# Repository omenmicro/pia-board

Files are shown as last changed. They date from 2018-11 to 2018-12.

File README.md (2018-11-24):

#OMEN PIA

Two 8bit serial port, designed for the [OMEN Computers](//github.com/osmibity/) with the system bus (Alpha, Bravo, Kilo, ...)

It uses the Motorola 68B21 PIA chip, or its 65xx equivalent 6521 (available from the WDC as [W65C21](http://westerndesigncenter.com/wdc/w65c21-chip.cfm)).

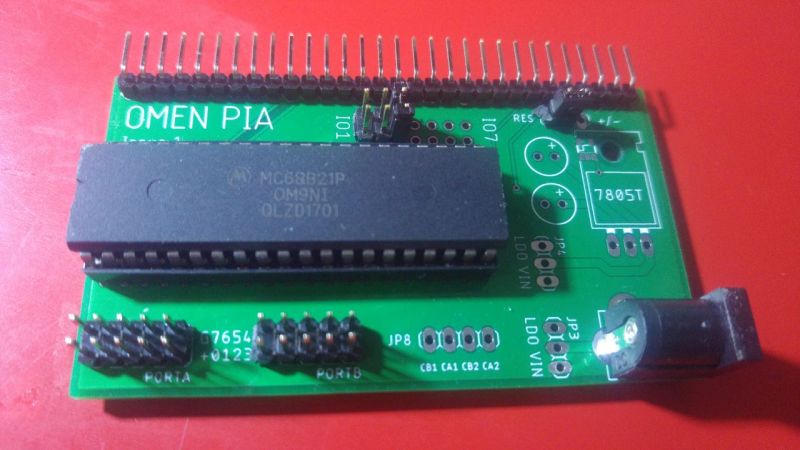
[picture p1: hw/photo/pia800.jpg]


Board allows some options:

- Power supply
  - Direct supply for 5 V
  - Voltage regulator for supply 7 - 12 V
- RESET invertor (OMEN Alpha has positive RESET, others have inverted /RESET)
- IO selector (you can select IO1 to IO7 using simple switch)

## Parts

- Motorola MC68B21 or equivalent (W65C21, R6521 etc)
- IO socket DIL, 40 pin, wide
- Pin headers for the OMEN Bus, IO switch, port data pins
- Switches for LDO and RESET polarity
- (Optionally) 7805 LDO voltage regulator + 2x capacitor 10M
- (Optionally) SMD invertor 74AHC1G04D for reverting the RESET polarity

## Usage

Select the right IOx address space. For addresses value of each IOx, consult your OMEN manual.

See [datasheet](docs/datasheet) to further detail about programming.

## Ports

Ports are connected to 2x5 pin header each. 

Each header has 8 data pin, Vcc and GND.

Special header JP8 has connected the CA1, CA2, CB1 and CB2 control pins.

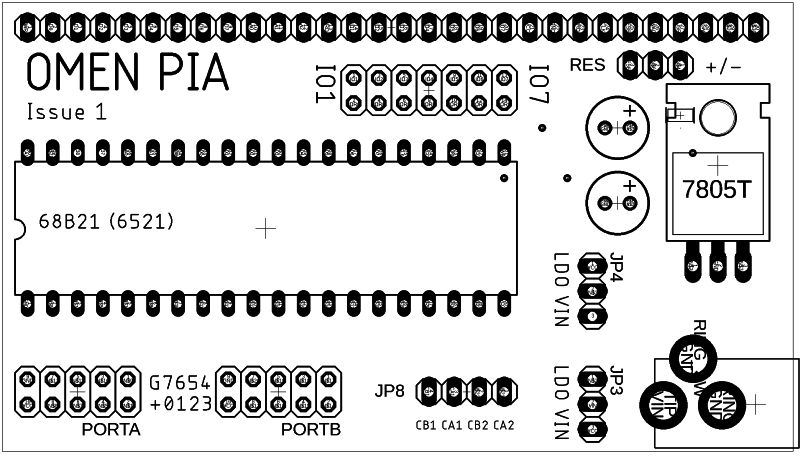
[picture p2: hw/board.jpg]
Board


### RESET circuit

For Kilo, Bravo etc. with inverted RESET, just connect RES pin "+" (1-2)
For Alpha: Solder the invertor 74AHC1G04D and connect RES pin "-" (2-3)
Alpha hack: just solder a wire between the middle pin of RES switch and VCC (e.g. pin 20 of PIA IC)

### Power circuit

If you have the regulated voltage supply 5V, you can connect it directly here. Please use two switches (JP3, JP4), both on "VIN" position. *CAUTION! Supply input is connected directly to the system Vcc, so leave the supply input on the CPU board not connected!*

You can use the place for the 7805 regulator (up to 2 A). Solder the regulator and tvo capacitors, and select option "LDO" on both switches JP3, JP4. Connect power supply 7 - 12 V. Use heat sink for the regulator!

If you does not use the dedicated power supply, just leave both switches open and omit the power supply connector, voltage regulator as well as both capacitors.

## System bus pinout

| Pin | Signal
| --- | ---
| 1  | /WR
| 2  | D0
| 3  | D1
| 4  | D2
| 5  | D3
| 6  | D4
| 7  | D5
| 8  | D6
| 9  | D7
| 10 |  A0
| 11 |  A1
| 12 |  A2 (not connected in OMEN PIA)
| 13 |  /RD
| 14 |  IO1 (active low)
| 15 |  IO2
| 16 |  IO3
| 17 |  IO4
| 18 |  IO5
| 19 |  IO6
| 20 |  IO7
| 21 |  Vcc
| 22 |  GND
| 23 |  IRQ (not connected in OMEN PIA)
| 24 |  Clock
| 25 |  /RESET
| 26 |  /WAIT (not connected in OMEN PIA)
| 27 |  /BUSRQ (not connected in OMEN PIA)
| 28 |  /BUSACK (not connected in OMEN PIA)
| 29 |  (Reserved for future use)
| 30 |  (Reserved for future use)

### License

[CERN OHL](LICENSE.txt)

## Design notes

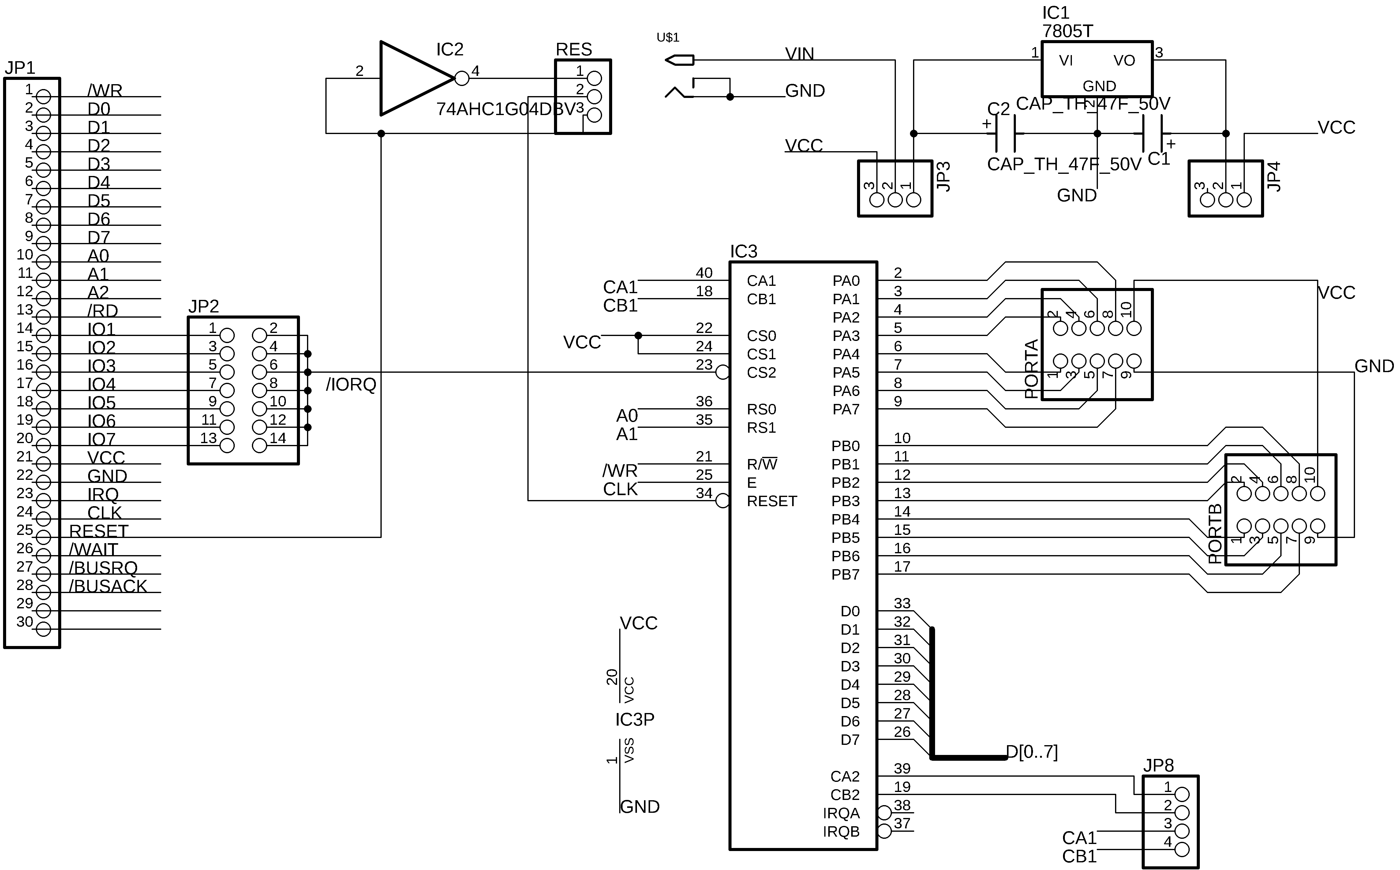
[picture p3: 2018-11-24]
hw/omenpia-schematics.png

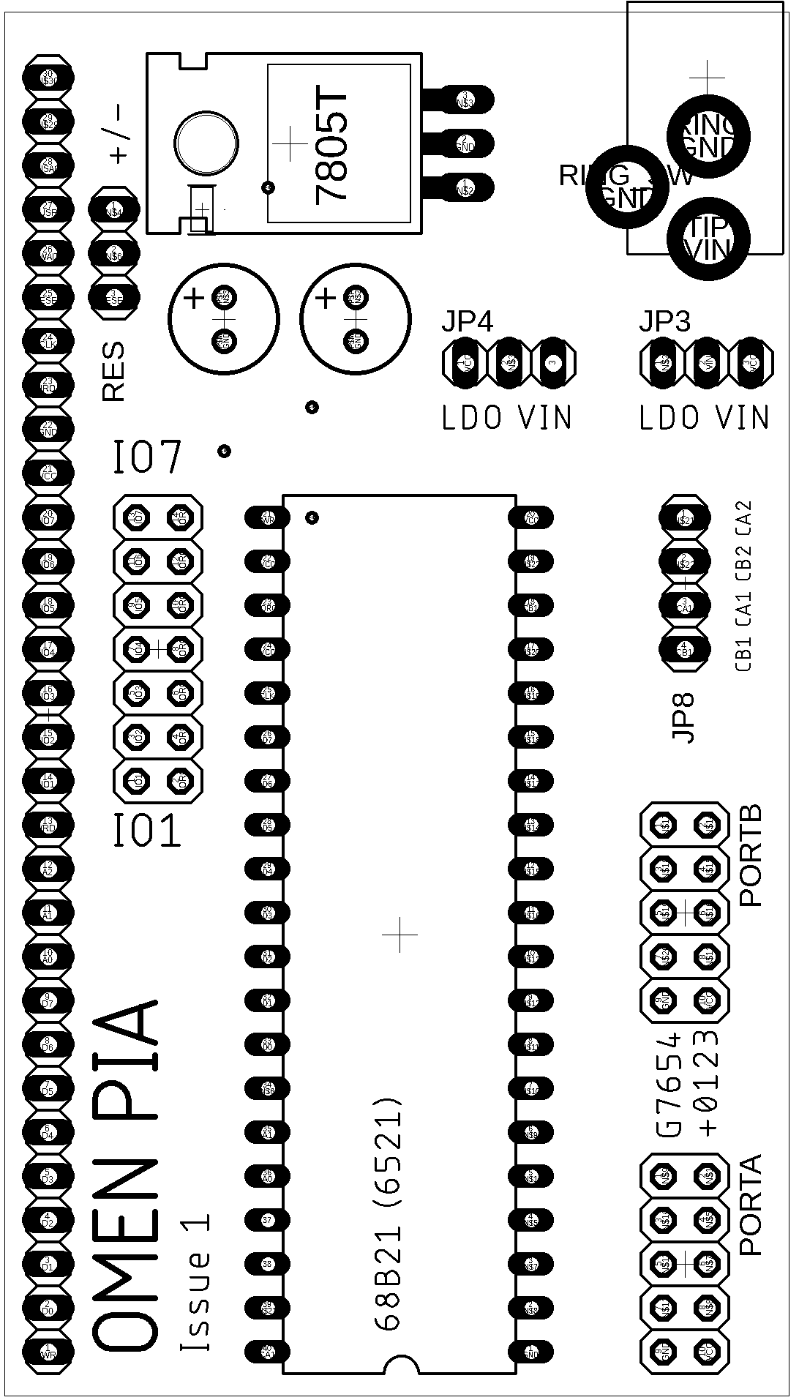
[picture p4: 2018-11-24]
hw/omenpia-board.png

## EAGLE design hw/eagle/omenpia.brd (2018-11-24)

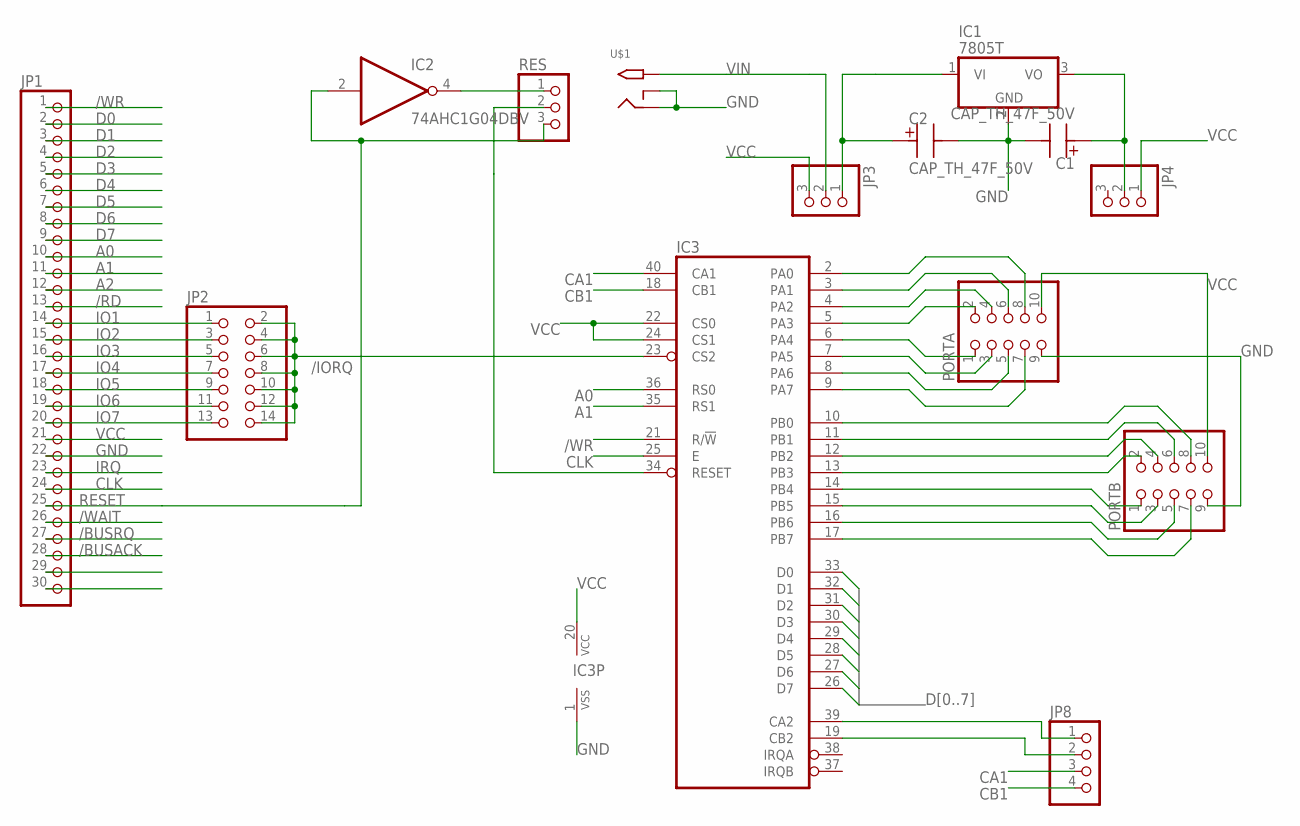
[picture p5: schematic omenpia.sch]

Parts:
C1, C2: CAP_TH_47F_50V; CAP_TH_P25_D63_POL
IC1: 7805T; TO220H
IC2: 74AHC1G04DBV; SOT23-5
IC3: 6821; DIL40
JP1: PINHD-1X30; 1X30
JP2: PINHD-2X7; 2X07
JP3, JP4: PINHD-1X3; 1X03
JP8: PINHD-1X4; 1X04
PORTA: PINHD-2X5; 2X05
PORTB: PINHD-2X5; 2X05
RES: PINHD-1X3; 1X03
U$1: 2.1MMJACKTHM; PJ-102A

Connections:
/BUSACK: JP1.28
/BUSRQ: JP1.27
/IORQ: IC3.23 (CS2), JP2.2, JP2.4, JP2.6, JP2.8, JP2.10, JP2.12, JP2.14
/RD: JP1.13
/WAIT: JP1.26
/WR: IC3.21 (R/!W), JP1.1
A0: IC3.36 (RS0), JP1.10
A1: IC3.35 (RS1), JP1.11
A2: JP1.12
CA1: IC3.40 (CA1), JP8.3
CB1: IC3.18 (CB1), JP8.4
CLK: IC3.25 (E), JP1.24
D0: IC3.33 (D0), JP1.2
D1: IC3.32 (D1), JP1.3
D2: IC3.31 (D2), JP1.4
D3: IC3.30 (D3), JP1.5
D4: IC3.29 (D4), JP1.6
D5: IC3.28 (D5), JP1.7
D6: IC3.27 (D6), JP1.8
D7: IC3.26 (D7), JP1.9
GND: C1.P$M, C2.P$M, IC1.2 (GND), IC2.3 (GND), IC3.1 (VSS), JP1.22, PORTA.9, PORTB.9, U$1.RING, U$1.RING_SW
IO1: JP1.14, JP2.1
IO2: JP1.15, JP2.3
IO3: JP1.16, JP2.5
IO4: JP1.17, JP2.7
IO5: JP1.18, JP2.9
IO6: JP1.19, JP2.11
IO7: JP1.20, JP2.13
IRQ: JP1.23
unnamed: IC3.5 (PA3), PORTA.2
unnamed: C2.P$P, IC1.1 (VI), JP3.1
unnamed: C1.P$P, IC1.3 (VO), JP4.2
unnamed: IC2.4 (O), RES.1
unnamed: IC3.4 (PA2), PORTA.4
unnamed: IC3.34 (RESET), RES.2
unnamed: IC3.3 (PA1), PORTA.6
unnamed: IC3.2 (PA0), PORTA.8
unnamed: IC3.6 (PA4), PORTA.1
unnamed: IC3.7 (PA5), PORTA.3
unnamed: IC3.8 (PA6), PORTA.5
unnamed: IC3.9 (PA7), PORTA.7
unnamed: IC3.10 (PB0), PORTB.8
unnamed: IC3.13 (PB3), PORTB.2
unnamed: IC3.12 (PB2), PORTB.4
unnamed: IC3.11 (PB1), PORTB.6
unnamed: IC3.14 (PB4), PORTB.1
unnamed: IC3.15 (PB5), PORTB.3
unnamed: IC3.16 (PB6), PORTB.5
unnamed: IC3.17 (PB7), PORTB.7
unnamed: IC3.39 (CA2), JP8.1
unnamed: IC3.19 (CB2), JP8.2
RESET: IC2.2 (I), JP1.25, RES.3
VCC: IC2.5 (VCC), IC3.20 (VCC), IC3.22 (CS0), IC3.24 (CS1), JP1.21, JP3.3, JP4.1, PORTA.10, PORTB.10
VIN: JP3.2, U$1.TIP

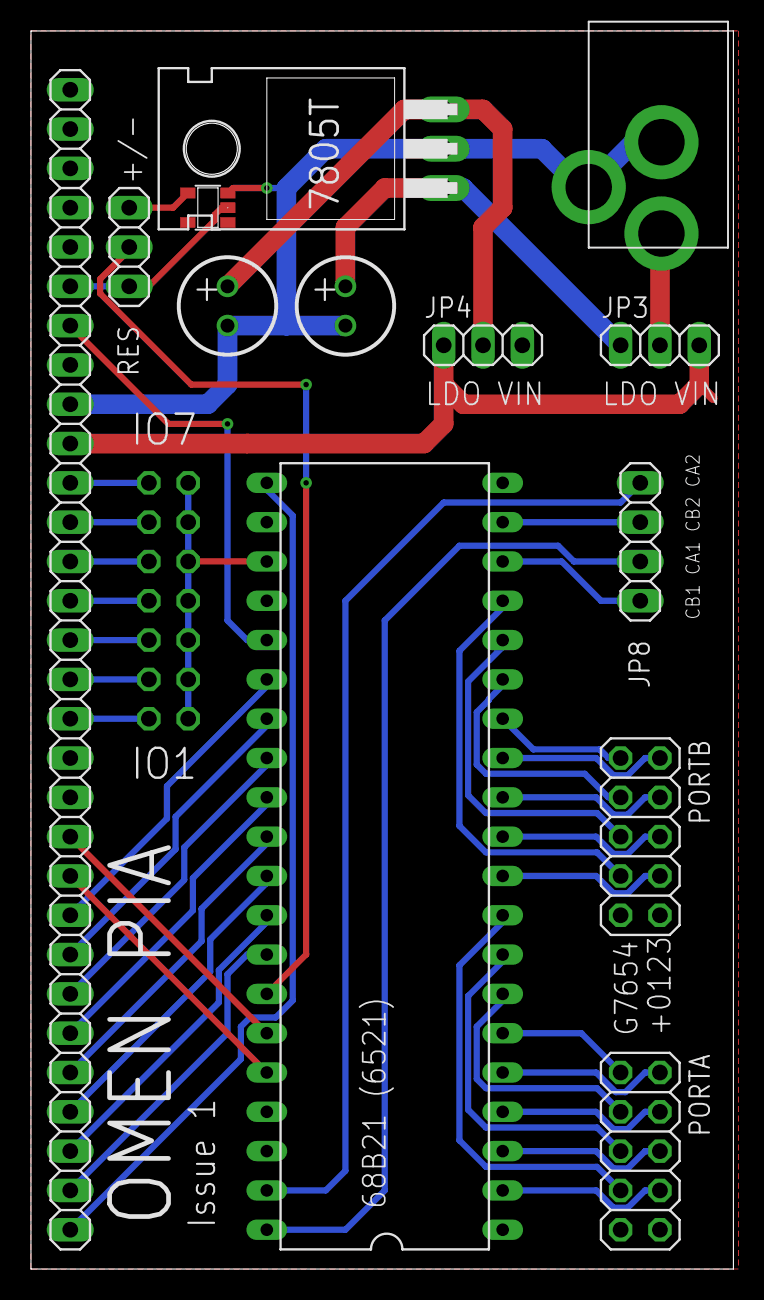
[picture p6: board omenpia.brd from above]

Board: 2 copper layers, 45.4 x 80.0 mm, 14 parts (1 on the bottom side), 48 nets.

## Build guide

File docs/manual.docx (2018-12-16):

OMEN PIA / issue 1

Technical Documentation

INTRODUCTION

===========

The OMEN PIA kit is a peripheral circuit for the OMEN series computets. It features:

- Motorola MC68B21 PIA
- Two 8bit parallel ports
- four control signals
- Power supply /optional/

ASSEMBLY INSTRUCTIONS

===================

1. Solder sockets for the integrated circuits
2. Test all soldered connections
  a. Test if all pins are well connected
  b. Check if GND is not short connected to Vcc
  c. Check if each IC has properly connected GND and Vcc
3. Solder all passive parts
4. Solder voltage regulator, if necessary
5. Solder RESET invertor for OMEN Alpha
6. Set switches to the proper configuration

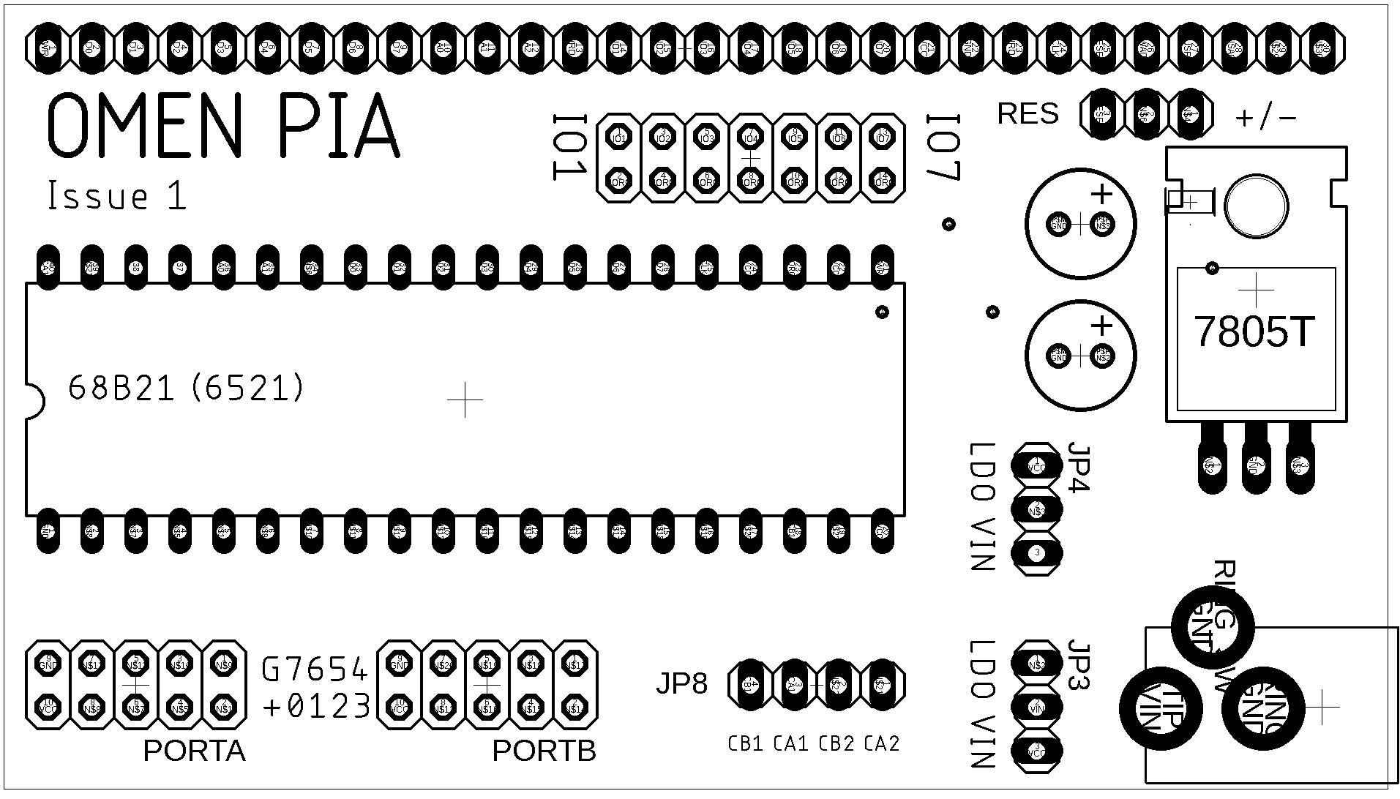
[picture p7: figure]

THE BOARD

========

Jumpers and pin headers

IO1-IO7: Selects the IO enable signal. OMEN computers has seven free /IO select signals, so you can chose the right one for you.

RES: All OMEN computers /Bravo, Kilo, .../ has /RESET active in log. 0. Only Alpha has a positive RESET, active in log. 1. For Bravo or Kilo just connect pins 1 and 2 - left and middle, marked as “+/” For Alpha connect middle and right, marked “/-“ and solder the SMD invertor 74AHC1G04, or just connect the middle pin to the VCC.

JP3, JP4: Only if you are planning to use the external power supply. Use two jumpers and connect them into the “VIN” position if voltage input is 5 V exactly. In the case you have non*regulated power supply 7 – 12 V, you have to connect both switches to the “LDO” position. You have to solder a 7805 voltage regulator and two polarized capacitors.

CAUTION
======

In the case you are using the PIA power supply, please do not connect the OMEN CPU board power supply together.

In the case you do not want to use PIA power supply circuit, just leave the JP3, JP4, C1, C2 and 7805 not connected.

OMEN ALPHA
=========

When connecting the OMEN PIA to the OMEN Alpha computer, you HAVE TO:

- solder the inverter 74AHC1G04 and connect the RES pins 2 and 3, marked as “slash – minus”

OR

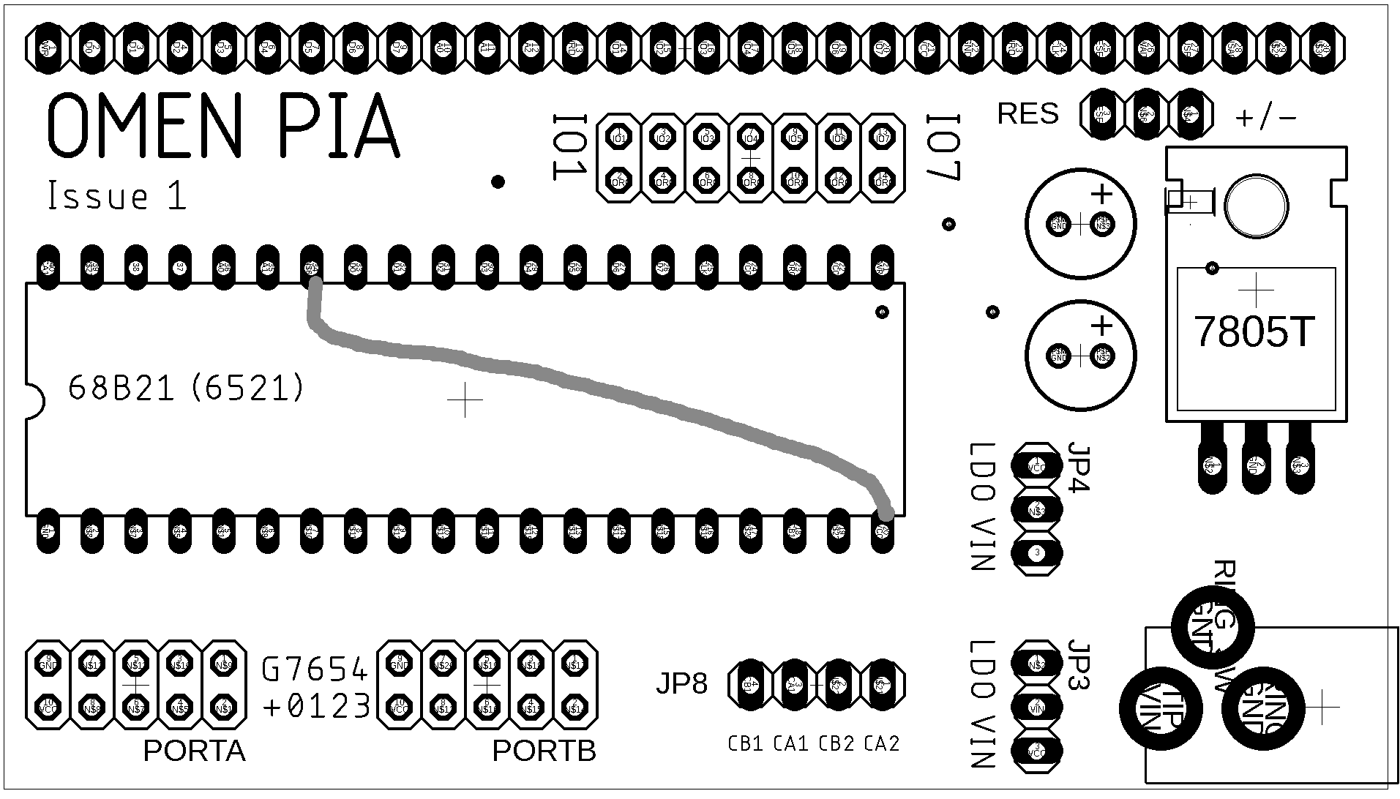
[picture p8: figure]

- connect the PIA pin 34 with the PIA pin 20 and leave RES unconnected. Use the resistor 10k. The resistance is not critical. You can use the simple wire connection too.

SYSTEM APPLICATION CONNECTOR

=========================

This connector is on the right edge of board. Pin 1 is on the upper side, next to the SYSTEM label.

Pins:

1 /WR
2 D0
3 D1
4 D2
5 D3
6 D4
7 D5
8 D6
9 D7
10 A0
11 A1
12 A2
13 /RD Bravo, Kilo Alpha
14 IO1 --- 9000h – 93FFh --- 20h – 27h
15 IO2 --- 8800h – 8BFFh --- 10h – 17h
16 IO3 --- 9800h – 9BFFh --- 30h – 37h
17 IO4 --- 8400h – 87FFh --- 00h – 0Fh
18 IO5 --- 9400h – 97FFh --- 20h – 2Fh
19 IO6 --- 8C00h – 8FFFh --- 10h – 1Fh
20 IO7 --- 9C00h – 9FFFh --- 30h – 3Fh
21 Vcc
22 GND
23 IRQ
24 PHI2
25 /RESET --- see the comment above
26 /WAIT
27 /BUSRQ
28 /BUSACK

OMEN Computers - - - https://github.com/osmibity - - - Page: 1

OMEN PIA ========
